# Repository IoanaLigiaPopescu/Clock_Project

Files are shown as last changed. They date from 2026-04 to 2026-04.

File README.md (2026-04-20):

BOM

Reference | Qty | Value / Part | JLC Parts Link | Datasheet
U1 | 1 | nRF52840 | https://jlcpcb.com/parts/componentSearch?searchTxt=nRF52840 | https://infocenter.nordicsemi.com/pdf/nRF52840_PS_v1.1.pdf
IC1 | 1 | BQ25180YBGR | https://jlcpcb.com/parts/componentSearch?searchTxt=BQ25180YBGR | https://www.ti.com/lit/ds/symlink/bq25180.pdf
IC2 | 1 | DRV2605YZFR | https://jlcpcb.com/parts/componentSearch?searchTxt=DRV2605YZFR | https://www.ti.com/lit/ds/symlink/drv2605.pdf
IC3 | 1 | BMA421 | https://jlcpcb.com/parts/componentSearch?searchTxt=BMA421 | https://www.bosch-sensortec.com/media/boschsensortec/downloads/datasheets/bst-bma421-ds000.pdf
IC9 | 1 | RT6160AWSC | https://jlcpcb.com/parts/componentSearch?searchTxt=RT6160AWSC | https://www.richtek.com/assets/product_file/RT6160A/DS6160A-00.pdf
U3 | 1 | MAX17048G+T10 | https://jlcpcb.com/parts/componentSearch?searchTxt=MAX17048G+T10 | https://www.analog.com/media/en/technical-documentation/data-sheets/MAX17048-MAX17049.pdf
D3 | 1 | USBLC6-2SC6Y | https://jlcpcb.com/parts/componentSearch?searchTxt=USBLC6-2SC6Y | https://www.st.com/resource/en/datasheet/usblc6-2.pdf
Q1 | 1 | DMG2305UX-7 | https://jlcpcb.com/parts/componentSearch?searchTxt=DMG2305UX-7 | https://www.diodes.com/assets/Datasheets/DMG2305UX.pdf
Q3 | 1 | SI1308EDL-T1-GE3 | https://jlcpcb.com/parts/componentSearch?searchTxt=SI1308EDL | https://www.vishay.com/docs/63399/si1308edl.pdf
J1 | 1 | 503480-2400 | https://jlcpcb.com/parts/componentSearch?searchTxt=503480-2400 | https://www.molex.com/pdm_docs/sd/5034802400_sd.pdf
J2 | 1 | TC2030-IDC | https://jlcpcb.com/parts/componentSearch?searchTxt=TC2030-IDC | https://www.tag-connect.com/wp-content/uploads/bsk-pdf-manager/TC2030-IDC-NL.pdf
J4 | 1 | KH-TYPE-C-16P | https://jlcpcb.com/parts/componentSearch?searchTxt=KH-TYPE-C-16P | https://www.kinghelm.net/uploadfiles/file/20231201/KH-TYPE-C-16P.pdf
ANT1 | 1 | 2450AT18B100E | https://jlcpcb.com/parts/componentSearch?searchTxt=2450AT18B100E | https://www.kyocera-avx.com/docs/techinfo/2450AT18B100.pdf
L7 | 1 | FTC252012SR47MBCA | https://jlcpcb.com/parts/componentSearch?searchTxt=FTC252012SR47MBCA | https://www.fenghua-advanced.com/upload/FTC252012.pdf
SW_DN,SW_ENT,SW_UP | 3 | EVP-AKE31A | https://jlcpcb.com/parts/componentSearch?searchTxt=EVP-AKE31A | https://industrial.panasonic.com/cdbs/www-data/pdf/ABH0000/ABH0000CE116.pdf
X1 | 1 | 32MHz Crystal | https://jlcpcb.com/parts/componentSearch?searchTxt=32MHz crystal 2016 | https://ecsxtal.com/store/pdf/ECS-2016MV.pdf
X2 | 1 | 32.768kHz Crystal | https://jlcpcb.com/parts/componentSearch?searchTxt=32.768kHz crystal 3215 | https://abracon.com/Resonators/ABS07.pdf
C* | multiple | Capacitors 0201/0402 | https://jlcpcb.com/parts/componentSearch?searchTxt=capacitor 0402 | https://www.murata.com/products/productdata/8796745949214/mlcc02e.pdf
R* | multiple | Resistors 0201 | https://jlcpcb.com/parts/componentSearch?searchTxt=resistor 0201 | https://www.yageo.com/upload/media/product/productsearch/datasheet/rchip/PYu-RC_Group_51_RoHS_L_12.pdf
L1,L2,L3,L5 | multiple | Inductors SMD | https://jlcpcb.com/parts/componentSearch?searchTxt=smd inductor | https://www.murata.com/products/productdata/8797098139678/ENFA0008.pdf
TP* | 14 | Test Pads | https://jlcpcb.com/parts/componentSearch?searchTxt=test pad pcb | https://www.keystone-europe.com/downloads/datasheets/5000.pdf

FUNCTIONALITATE

Proiectul este o platformă embedded portabilă bazată pe microcontroller-ul nRF52840, proiectată pentru aplicații low-power cu interfață vizuală E-Paper, alimentare din baterie Li-Po, conectivitate USB-C, feedback haptic și senzori de mișcare. Toate componentele sunt montate pe stratul Top al plăcii PCB.

Microcontroller-ul principal este nRF52840. Acesta integrează procesor ARM Cortex-M4F la 64 MHz, memorie Flash 1 MB, RAM 256 KB și transceiver radio 2.4 GHz compatibil Bluetooth Low Energy. Comunicarea RF se realizează printr-o antenă ceramică 2.45 GHz conectată printr-o rețea de adaptare de impedanță formată din L1, C3, C4 și pad opțional C22 pentru tuning RF. Oscilatorul principal extern este de 32 MHz (X1), iar oscilatorul low-power RTC este de 32.768 kHz (X2).

Interfața USB este realizată prin conector USB Type-C J4. Liniile D+ și D- sunt conectate direct la microcontroller pentru comunicație USB Full Speed. Pinii CC1 și CC2 sunt configurați prin rezistențe de 5.1 kΩ la masă pentru mod Device. Protecția ESD a liniilor USB este realizată de componenta USBLC6-2SC6Y.

Alimentarea principală provine din baterie Li-Po reîncărcabilă. Circuitul de încărcare este BQ25180YBGR, care gestionează încărcarea de la VBUS (5 V USB), controlul curentului de încărcare și monitorizarea stării prin interfață I2C. Tensiunea bateriei este disponibilă pe net-ul BAT și filtrată local prin condensatorul C39.

Conversia de tensiune este realizată de RT6160AWSC, convertor buck-boost controlat prin I2C. Acesta poate ridica sau coborî tensiunea bateriei pentru a genera rail-ul stabilizat necesar sistemului. Etajul de putere utilizează inductanța L7 și condensatorii C23, C24 la intrare respectiv C25, C32 la ieșire.

Monitorizarea nivelului bateriei este realizată de MAX17048G+T10, fuel gauge conectat la magistrala I2C. Acesta măsoară tensiunea celulei și estimează procentul de încărcare, oferind semnal ALERT către microcontroller.

Senzorul de mișcare utilizat este BMA421, accelerometru triaxial low-power. Comunicarea cu microcontroller-ul se face prin I2C, iar liniile INT1 și INT2 permit detectarea de evenimente precum mișcare, tap sau wake-up. Alimentarea senzorului este filtrată prin C18 și C19.

Feedback-ul tactil este realizat prin DRV2605YZFR, driver dedicat pentru motoare ERM/LRA. Acesta este controlat prin I2C și poate genera modele de vibrație prestabilite. Ieșirile OUT+ și OUT- sunt rutate către test point-urile TP_OP și TP_ON.

Interfața vizuală este un display E-Paper conectat prin conector FPC J1 cu 24 pini. Controlul se face de la microcontroller prin semnale dedicate (SPI și GPIO), inclusiv EPD_CS. Circuitul auxiliar al display-ului folosește MOSFET-ul Q3 și componente pasive dedicate pentru generarea tensiunilor necesare panoului.

Interfața utilizator este compusă din trei butoane tactile SW_UP, SW_ENT și SW_DN, conectate la GPIO-urile microcontroller-ului. Acestea permit navigare în meniu și control local fără dispozitive externe.

Programarea și depanarea hardware se realizează prin conectorul J2 compatibil SWD. Sunt disponibile liniile SWDIO, SWDCLK, RESET și SWO. În plus, placa include multiple test point-uri pentru 3.3V, GND, VBAT, SDA, SCL și alte semnale utile în validare.

Magistrala principală de comunicație internă este I2C, partajată între charger, convertorul DC/DC, fuel gauge, IMU și driverul haptic. Aceasta reduce numărul de pini utilizați și simplifică layout-ul PCB.

Estimarea consumului de energie depinde de modul de operare. nRF52840 în sleep poate coborî la ordinul microamperilor. În transmisie radio consumul este de ordinul miliamperilor. Display-ul E-Paper consumă aproape zero în regim static și energie doar la refresh. IMU-ul BMA421 funcționează în mod low-power la câțiva microamperi. Driverul haptic consumă semnificativ doar în timpul vibrației. Autonomia sistemului este favorizată de utilizarea componentelor low-power și a afișajului bistabil.

PCB-ul este proiectat pe 4 straturi, cu planuri dedicate de masă pentru integritate de semnal, zgomot redus și performanță RF mai bună. Toate componentele sunt plasate pe stratul superior pentru asamblare simplificată SMT.

PINI

nRF52840 este microcontroller-ul principal al sistemului și controlează toate perifericele hardware: alimentare, senzori, display, comunicație USB și debugging. Alegerea pinilor a fost făcută pentru a folosi interfețele hardware dedicate și pentru a simplifica rutarea PCB.

Pinii D+ și D- sunt conectați la conectorul USB-C prin protecția ESD D3. Aceștia sunt utilizați pentru comunicație USB nativă, programare și transfer de date.

Pinii SWDIO, SWDCLK, RESET și SWO sunt scoși la conectorul J2 pentru programare și debugging hardware.

P0.07 și P0.08 sunt utilizați ca SDA și SCL pentru magistrala I2C. Pe această magistrală sunt conectate BQ25180 (charger), RT6160A (buck-boost), MAX17048 (fuel gauge), BMA421 (IMU) și DRV2605 (driver haptic). Alegerea I2C reduce numărul de pini utilizați.

P1.08 și P1.09 sunt conectați la INT1 și INT2 de la accelerometru, pentru wake-up la mișcare și notificări hardware.

P0.11 este utilizat pentru semnal de interrupt din zona de power management.

P0.12 este utilizat pentru controlul subsistemului haptic.

P0.06 este utilizat pentru EPD_CS, semnal de selecție al display-ului E-Paper. Restul pinilor display-ului folosesc SPI și GPIO pentru control.

P0.04 și P0.05 sunt pini analogici utilizați pentru măsurători ADC, de exemplu monitorizare tensiune.

Pinul ANT este conectat la rețeaua RF L1, C3, C4 și antena ceramică. Traseul este menținut scurt pentru performanță radio bună.

XC1 și XC2 sunt conectați la cristalul de 32 MHz, iar XL1 și XL2 la cristalul de 32.768 kHz pentru RTC low-power.

PCB-ul este pe 4 straturi, cu plane de masă dedicate și toate componentele pe Top Layer. Antena este plasată la marginea plăcii cu keepout RF. Zona de alimentare este separată de zona RF, iar test point-urile pentru 3.3V, GND, VBAT, SWD și I2C permit depanare rapidă. Designul este optimizat pentru consum redus și funcționare pe baterie.

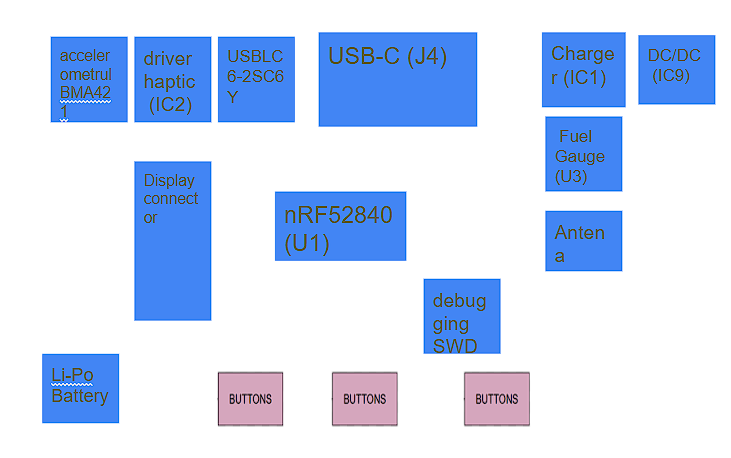
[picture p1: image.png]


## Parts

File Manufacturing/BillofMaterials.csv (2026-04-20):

Reference Designators | Quantity | Description | Package | Value | Manufacturer | Manufacturer Part Number | Vendor | Vendor Part Number | Top/Bottom
 | 1 | PCB Board | Board
ANT1 | 1 | Antennas 2.45GHz ANTENNA | 2450AT18B100E_ANTC3216X140N | 2450AT18B100E |  |  |  |  | Top
C1, C2, C17, C18 | 4 | Generic chip capacitor | NORDIC_NRF_3_RESC0201_L | 12pF |  |  |  |  | Top
C1-EP-DR | 1 | CAPACITOR, European symbol | ESP32_WROVER_EAGLE-LTSPICE_C0402 | 10µF |  |  |  |  | Top
C2-EP-DR | 1 | CAPACITOR, European symbol | ESP32_WROVER_EAGLE-LTSPICE_C0402 | 4.7uF/25V |  |  |  |  | Top
C3, C4 | 2 | Generic chip capacitor | NORDIC_NRF_3_RESC0201_L | 1pF |  |  |  |  | Top
C5, C7, C8, C12, C19 | 5 | Generic chip capacitor | NORDIC_NRF_3_RESC0201_L | 100nF |  |  |  |  | Top
C6, C14, C20, C21 | 4 | CAPACITOR, European symbol | ESP32_WROVER_EAGLE-LTSPICE_C0402 | 4.7µF |  |  |  |  | Top
C9 | 1 | Generic chip capacitor | NORDIC_NRF_3_RESC0201_L | 820pF |  |  |  |  | Top
C10, C13, C22 | 3 | Generic chip capacitor | NORDIC_NRF_3_RESC0201_L |  |  |  |  |  | Top
C11 | 1 | Generic chip capacitor | NORDIC_NRF_3_RESC0201_L | 100pF |  |  |  |  | Top
C15 | 1 | CAPACITOR, European symbol | ESP32_WROVER_EAGLE-LTSPICE_C0402 | 1.0µF |  |  |  |  | Top
C16 | 1 | Generic chip capacitor | NORDIC_NRF_3_RESC0201_L | 47nF |  |  |  |  | Top
C23, C27, C34, C42 | 4 | Check availability | CAPC0201X13N | 0.1uF |  |  |  |  | Top
C24, C39 | 2 | CAPACITOR, European symbol | ESP32_WROVER_EAGLE-LTSPICE_C0402 | 10uF |  |  |  |  | Top
C25, C33 | 2 | CAPACITOR, European symbol | ESP32_WROVER_EAGLE-LTSPICE_C0402 | 22uF |  |  |  |  | Top
C29, C30, C31, C32, C37, C38 | 6 | Check availability | CAPC0201X13N | 1uF |  |  |  |  | Top
C43 | 1 | CAPACITOR, European symbol | ESP32_WROVER_EAGLE-LTSPICE_C0402 | 4.7uF |  |  |  |  | Top
D2, D4, D5 | 3 | ON SEMICONDUCTOR - MBR0530 - DIODE, SCHOTTKY, 0.5A, 30V, SOD-123 | SOD3716X135N | MBR0530 |  |  |  |  | Top
D3 | 1 | Low Cap. ESD Protection Auto SOT-23-6 STMicroelectronics USBLC6-2SC6Y, Dual Uni-Directional TVS Diode Array, 6-Pin SOT-23 | SOT95P280X145-6N | USBLC6-2SC6Y |  |  |  |  | Top
EPD_C1, EPD_C2, EPD_C6, EPD_C7, EPD_C8, EPD_C9, EPD_C10, EPD_C11, EPD_C12 | 9 | CAPACITOR, European symbol | ESP32_WROVER_EAGLE-LTSPICE_C0402 | 1uF/50V |  |  |  |  | Top
EPD_C5 | 1 | CAPACITOR, European symbol | ESP32_WROVER_EAGLE-LTSPICE_C0402 | 0.1uF/50V |  |  |  |  | Top
IC1 | 1 | Charger IC Lithium Ion/Polymer, Lithium Iron Phosphate 8-DSBGA (1.6x1.1) | BQ25180YBGR_BGA8C40P2X4_100X155X50 | BQ25180YBGR |  |  |  |  | Top
IC2 | 1 | Haptic Driver for ERM/LRA with Built-In Library and Smart Loop Architecture | DRV2605YZFR_BGA9C50P3X3_144X144X62 | DRV2605YZFR |  |  |  |  | Top
IC3 | 1 | Accelerometers Triaxial low-g 12bit Acceleration Sensor | BMA423_BMA423 | BMA421 |  |  |  |  | Top
IC9 | 1 | Buck-Boost Regulator Positive Output Step-Up/Step-Down I2C DC-DC Controller IC 15-WL-CSP (BSC) (1.4x2.3) | RT6160AWSC_BGA15C40P3X5_140X230X60 | RT6160AWSC |  |  |  |  | Top
J1 | 1 | FFC & FPC Connectors 0.5mm FPC RA SMT Dual Contact 24Ckt | 503480-2400_5034802400 | 503480-2400 |  |  |  |  | Top
J2 | 1 | CABLE ADAPTER 6 POS | TC2030-IDC_TC2030IDC | TC2030-IDC |  |  |  |  | Top
J4 | 1 | Check availability | KINGHELM_KH-TYPE-C-16P | KH-TYPE-C-16P |  |  |  |  | Top
L1 | 1 | Generic chip inductor | NORDIC_NRF_2_RESC0402_L | 3.9nH |  |  |  |  | Top
L2 | 1 | Generic chip inductor | NORDIC_NRF_2_RESC0402_L | 10µH |  |  |  |  | Top
L3 | 1 | Generic chip inductor | NORDIC_NRF_2_RESC0402_L | 15nH |  |  |  |  | Top
L5 | 1 |  | ESP32_C6_LIBRARY_2_IND_4828-WE-TPC_WRE | 68uH |  |  |  |  | Top
L7 | 1 | SMD / SMT Inductors (Coils), L=0.47?H, L x W x T : | MLP2016SR47MT0S1_INDC2016X100N | FTC252012SR47MBCA |  |  |  |  | Top
Q1 | 1 | P-channel MOSFETs | ESP32_WROVER_SPARKFUN-DISCRETESEMI_SOT23-3 | 20V/4.2A/52mΩ/1.4W DMG2305UX-7 |  |  |  |  | Top
Q3 | 1 | MOSFET N-Ch 30V 1.5A TrenchFET SC70 Vishay Si1308EDL-T1-GE3 N-channel MOSFET Transistor, 1.5 A, 30 V, 3-Pin SC-70 | SOT65P210X110-3N | SI1308EDL-T1-GE3 |  |  |  |  | Top
R_PWR_EPD, R2_EP_DR | 2 | 7.68k 0201 Thin Film Surface Mount Fixed Resistor +/-0.5% 0.031W CPF0201D7K68C1 | CPF0201D7K68C1_0201 | 10K |  |  |  |  | Top
R_TYPE_SEL | 1 | 7.68k 0201 Thin Film Surface Mount Fixed Resistor +/-0.5% 0.031W CPF0201D7K68C1 | CPF0201D7K68C1_0201 | 2.2 |  |  |  |  | Top
R1_EP_DR | 1 | 7.68k 0201 Thin Film Surface Mount Fixed Resistor +/-0.5% 0.031W CPF0201D7K68C1 | CPF0201D7K68C1_0201 | 0.47 |  |  |  |  | Top
R1_USB, R2_USB | 2 | 7.68k 0201 Thin Film Surface Mount Fixed Resistor +/-0.5% 0.031W CPF0201D7K68C1 | CPF0201D7K68C1_0201 | 5K1 |  |  |  |  | Top
R2, R3, R4 | 3 | 7.68k 0201 Thin Film Surface Mount Fixed Resistor +/-0.5% 0.031W CPF0201D7K68C1 | CPF0201D7K68C1_0201 | 0 |  |  |  |  | Top
R5, R7, R8, R9 | 4 | 7.68k 0201 Thin Film Surface Mount Fixed Resistor +/-0.5% 0.031W CPF0201D7K68C1 | CPF0201D7K68C1_0201 | 10k |  |  |  |  | Top
R17, R18 | 2 | 7.68k 0201 Thin Film Surface Mount Fixed Resistor +/-0.5% 0.031W CPF0201D7K68C1 | CPF0201D7K68C1_0201 | 3K3 |  |  |  |  | Top
SJ1 | 1 | SMD solder JUMPER | JUMPER_SJ |  |  |  |  |  | Top
SW_DN, SW_ENT, SW_UP | 3 |  | SW_EVP-AKE31A_PAN | 2025-10-22_07-23-44_LIBRARY_EVP-AKE31ASW_EVP-AKE31A_PAN |  |  |  |  | Top
TP_3.3V, TP_3V3, TP_BAT_GND, TP_GND, TP_ON, TP_OP, TP_RESET, TP_SCL, TP_SDA, TP_SWDCLK, TP_SWDIO, TP_SWO, TP_VBAT, TP_VREG | 14 | Test pad | HECTOR_WATCH_1_TP20R | HECTOR_WATCH_1_TPTP20R |  |  |  |  | Top
U1 | 1 | nRF52840 | NORDIC_NRF_4_AQFN50P700X700X85_HS-74N | NRF52840_QF |  |  |  |  | Top
U3 | 1 | Check availability | SON50P200X200X80-9N | MAX17048G+T10 |  |  |  |  | Top
X1 | 1 |  | NORDIC_NRF_BT-XTAL_2016_N | 32MHz |  |  |  |  | Top
X2 | 1 |  | NORDIC_NRF_1_XTAL_3215_N | 32.768kHz |  |  |  |  | Top

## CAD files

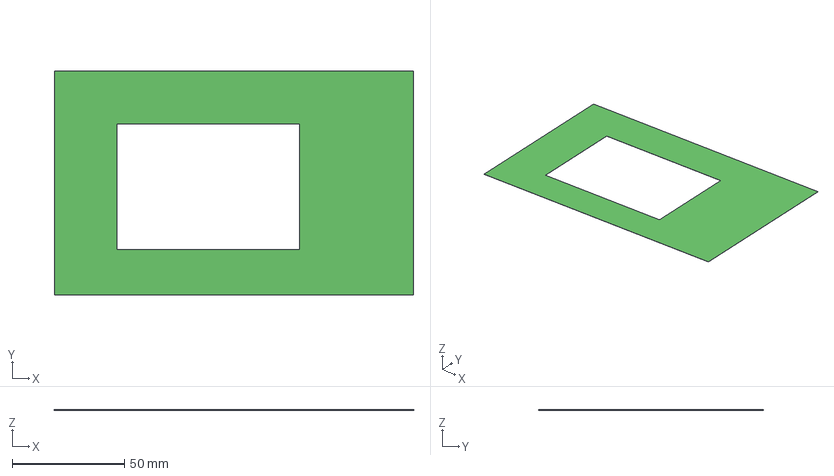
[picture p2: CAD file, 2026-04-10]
3d/1-soldermask.step
160.0 x 100.0 x 0.0804 mm

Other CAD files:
pcb/pcb.f3d

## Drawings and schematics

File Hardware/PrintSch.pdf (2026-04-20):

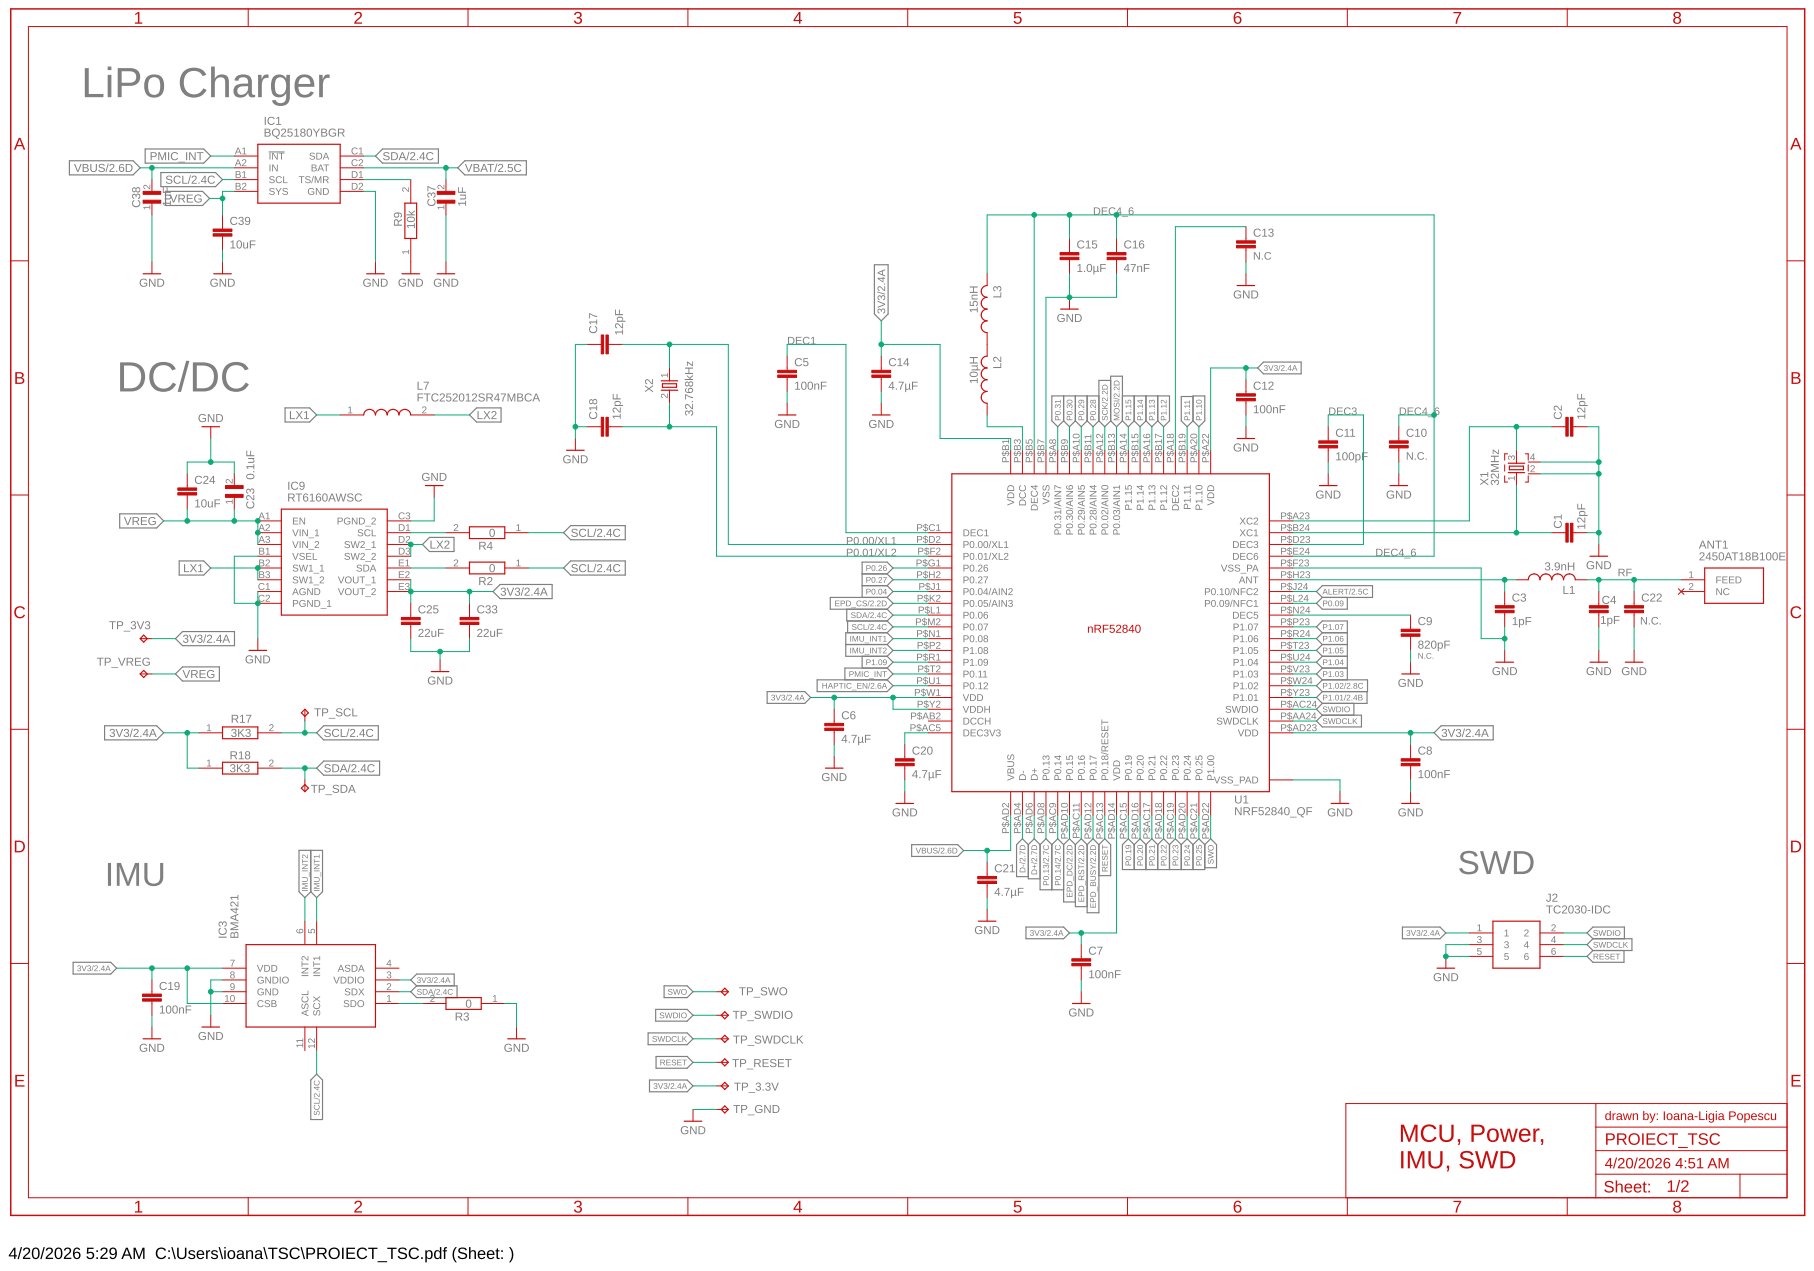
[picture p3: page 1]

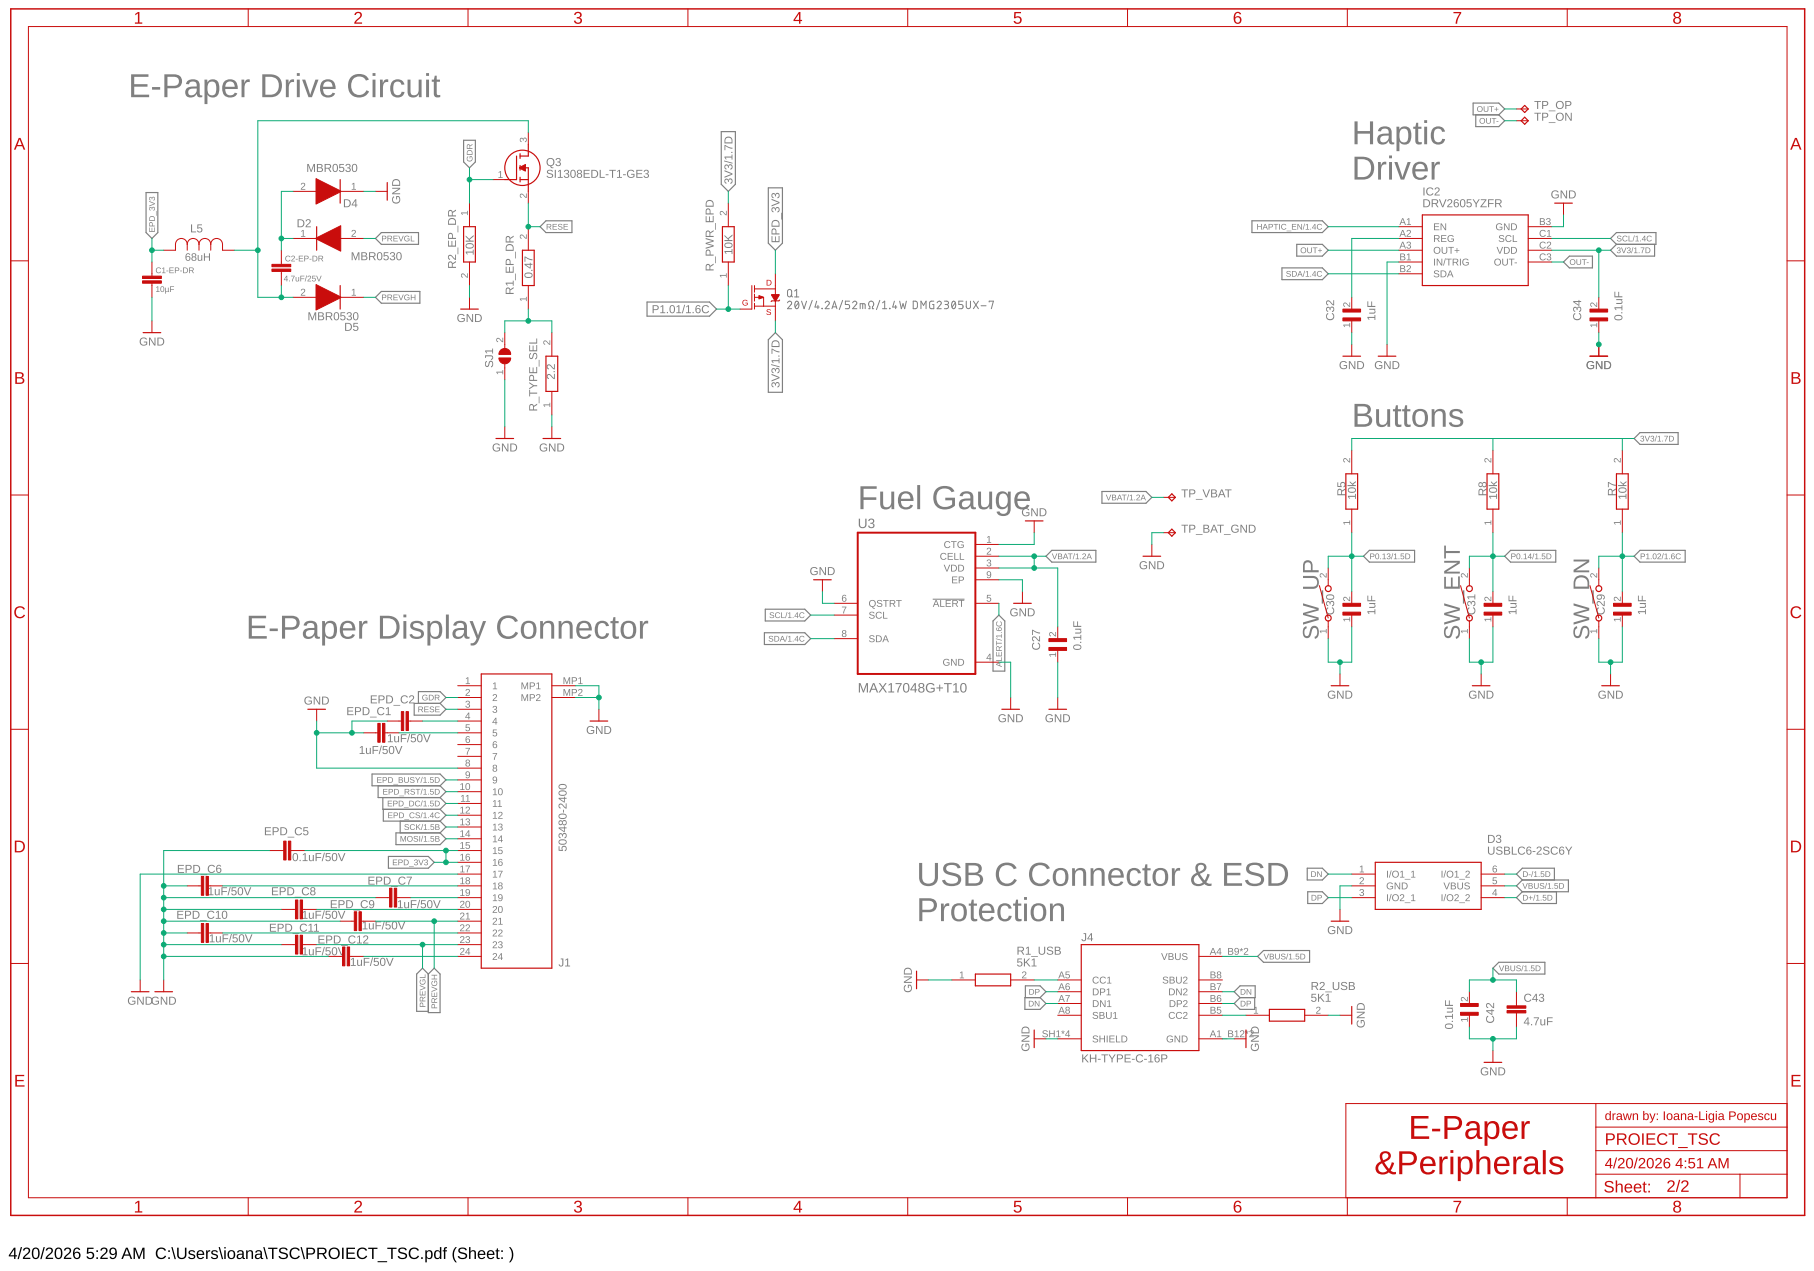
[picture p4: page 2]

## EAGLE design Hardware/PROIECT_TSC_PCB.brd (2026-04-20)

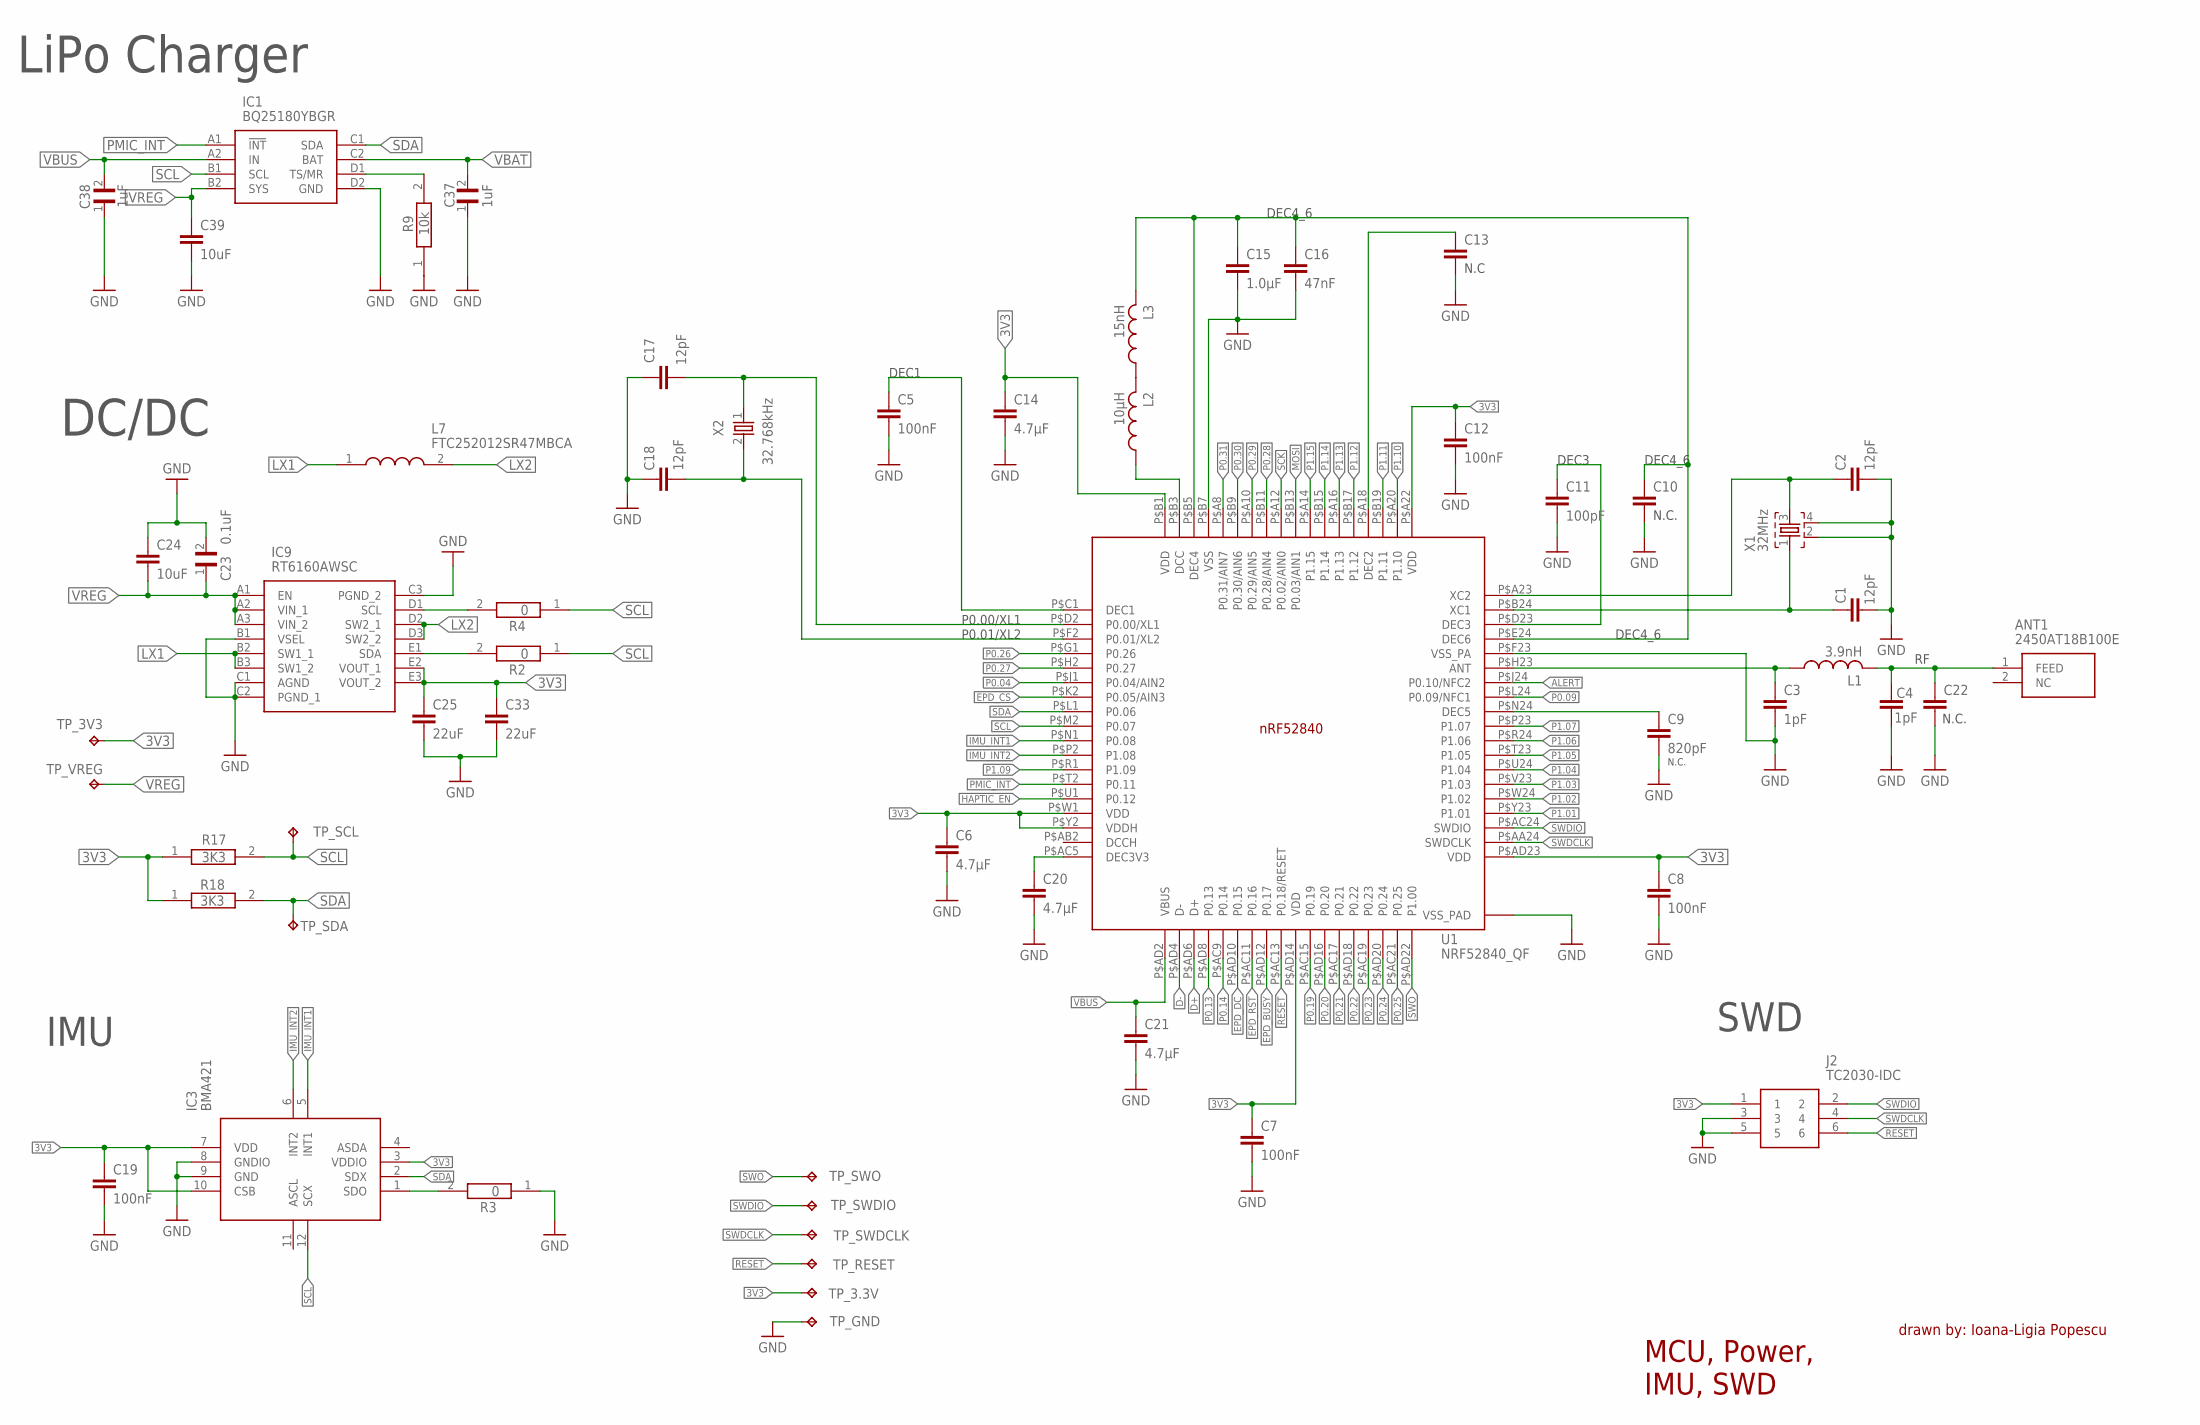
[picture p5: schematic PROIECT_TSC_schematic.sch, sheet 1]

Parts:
ANT1: 2450AT18B100E; 2450AT18B100E_ANTC3216X140N
C1, C2, C17, C18: 12pF; NORDIC_NRF_3_RESC0201_L
C3, C4: 1pF; NORDIC_NRF_3_RESC0201_L
C5, C7, C8, C12, C19: 100nF; NORDIC_NRF_3_RESC0201_L
C6, C14, C20, C21: 4.7µF; ESP32_C6_LIBRARY_1_ESP32_WROVER_EAGLE-LTSPICE_C0402
C9: 820pF; NORDIC_NRF_3_RESC0201_L
C10, C13, C22: NORDIC_NRF_3_CAPACITOR_0201_L; NORDIC_NRF_3_RESC0201_L
C11: 100pF; NORDIC_NRF_3_RESC0201_L
C15: 1.0µF; ESP32_C6_LIBRARY_1_ESP32_WROVER_EAGLE-LTSPICE_C0402
C16: 47nF; NORDIC_NRF_3_RESC0201_L
C23: 0.1uF; GRM011R60J152KE01L_2_CAPC0201X13N
C24, C39: 10uF; ESP32_C6_LIBRARY_1_ESP32_WROVER_EAGLE-LTSPICE_C0402
C25, C33: 22uF; ESP32_C6_LIBRARY_1_ESP32_WROVER_EAGLE-LTSPICE_C0402
C37, C38: 1uF; GRM011R60J152KE01L_2_CAPC0201X13N
IC1: BQ25180YBGR; BQ25180YBGR_BGA8C40P2X4_100X155X50
IC3: BMA421; BMA423_BMA423
IC9: RT6160AWSC; RT6160AWSC_BGA15C40P3X5_140X230X60
J2: TC2030-IDC; TC2030-IDC_TC2030IDC
L1: 3.9nH; NORDIC_NRF_2_RESC0402_L
L2: 10µH; NORDIC_NRF_2_RESC0402_L
L3: 15nH; NORDIC_NRF_2_RESC0402_L
L7: FTC252012SR47MBCA; MLP2016SR47MT0S1_INDC2016X100N
R2, R3, R4: 0; CPF0201D7K68C1_0201
R9: 10k; CPF0201D7K68C1_0201
R17, R18: 3K3; CPF0201D7K68C1_0201
TP_3.3V, TP_3V3: HECTOR_WATCH_1_TPTP20R; HECTOR_WATCH_1_TP20R
TP_GND: HECTOR_WATCH_1_TPTP20R; HECTOR_WATCH_1_TP20R
TP_RESET: HECTOR_WATCH_1_TPTP20R; HECTOR_WATCH_1_TP20R
TP_SCL: HECTOR_WATCH_1_TPTP20R; HECTOR_WATCH_1_TP20R
TP_SDA: HECTOR_WATCH_1_TPTP20R; HECTOR_WATCH_1_TP20R
TP_SWDCLK: HECTOR_WATCH_1_TPTP20R; HECTOR_WATCH_1_TP20R
TP_SWDIO: HECTOR_WATCH_1_TPTP20R; HECTOR_WATCH_1_TP20R
TP_SWO: HECTOR_WATCH_1_TPTP20R; HECTOR_WATCH_1_TP20R
TP_VREG: HECTOR_WATCH_1_TPTP20R; HECTOR_WATCH_1_TP20R
U1: NRF52840_QF; NORDIC_NRF_4_AQFN50P700X700X85_HS-74N
X1: 32MHz; NORDIC_NRF_BT-XTAL_2016_N
X2: 32.768kHz; NORDIC_NRF_1_XTAL_3215_N

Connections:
3V3: C6.1, C7.1, C8.1, C12.1, C14.1, C19.1, C25.1, C33.1, IC3.3 (VDDIO), IC3.7 (VDD), IC3.10 (CSB), IC9.E2 (VOUT_1), IC9.E3 (VOUT_2), J2.1, R17.1, R18.1, TP_3.3V.TP, TP_3V3.TP, U1.P$A22 (VDD), U1.P$AD14 (VDD), U1.P$AD23 (VDD), U1.P$B1 (VDD), U1.P$W1 (VDD), U1.P$Y2 (VDDH); also elsewhere on the board
ALERT: U1.P$J24 (P0.10/NFC2); also elsewhere on the board
D+: U1.P$AD6 (D+); also elsewhere on the board
D-: U1.P$AD4 (D-); also elsewhere on the board
EPD_BUSY: U1.P$AD12 (P0.17); also elsewhere on the board
EPD_CS: U1.P$K2 (P0.05/AIN3); also elsewhere on the board
EPD_DC: U1.P$AD10 (P0.15); also elsewhere on the board
EPD_RST: U1.P$AC11 (P0.16); also elsewhere on the board
GND: C1.1, C2.2, C3.2, C4.1, C5.2, C6.2, C7.2, C8.2, C9.2, C10.2, C11.2, C12.2, C13.2, C14.2, C15.2, C16.2, C17.2, C18.1, C19.2, C20.2, C21.2, C22.2, C23.2, C24.1, C25.2, C33.2, C37.1, C38.1, C39.2, IC1.D2 (GND), IC3.8 (GNDIO), IC3.9 (GND), IC9.B1 (VSEL), IC9.C1 (AGND), IC9.C2 (PGND_1), IC9.C3 (PGND_2), J2.3, J2.5, R3.1, R9.1, TP_GND.TP, U1.P$74 (VSS_PAD), U1.P$75 (VSS_PAD), U1.P$76 (VSS_PAD), U1.P$77 (VSS_PAD), U1.P$78 (VSS_PAD), U1.P$79 (VSS_PAD), U1.P$80 (VSS_PAD), U1.P$81 (VSS_PAD), U1.P$82 (VSS_PAD), U1.P$83 (VSS_PAD), U1.P$84 (VSS_PAD), U1.P$85 (VSS_PAD), U1.P$86 (VSS_PAD), U1.P$87 (VSS_PAD), U1.P$88 (VSS_PAD), U1.P$89 (VSS_PAD), U1.P$90 (VSS_PAD), U1.P$B7 (VSS), U1.P$F23 (VSS_PA), X1.2, X1.4; also elsewhere on the board
HAPTIC_EN: U1.P$U1 (P0.12); also elsewhere on the board
IMU_INT1: IC3.5 (INT1), U1.P$N1 (P0.08)
IMU_INT2: IC3.6 (INT2), U1.P$P2 (P1.08)
LX1: IC9.B2 (SW1_1), IC9.B3 (SW1_2), L7.1
LX2: IC9.D2 (SW2_1), IC9.D3 (SW2_2), L7.2
MOSI: U1.P$B13 (P0.03/AIN1); also elsewhere on the board
unnamed: IC1.D1 (TS/MR), R9.2
unnamed: IC9.D1 (SCL), R4.2
unnamed: C11.1, U1.P$D23 (DEC3)
unnamed: IC9.E1 (SDA), R2.2
unnamed: C13.1, U1.P$A18 (DEC2)
unnamed: C2.1, U1.P$A23 (XC2), X1.3
unnamed: C1.2, U1.P$B24 (XC1), X1.1
unnamed: L2.1, U1.P$B3 (DCC)
unnamed: L2.2, L3.1
unnamed: C10.1, C15.1, C16.1, L3.2, U1.P$B5 (DEC4), U1.P$E24 (DEC6)
unnamed: C9.1, U1.P$N24 (DEC5)
unnamed: C3.1, L1.1, U1.P$H23 (ANT)
unnamed: ANT1.1 (FEED), C4.2, C22.1, L1.2
unnamed: C5.1, U1.P$C1 (DEC1)
unnamed: C17.1, U1.P$D2 (P0.00/XL1), X2.1
unnamed: C18.2, U1.P$F2 (P0.01/XL2), X2.2
unnamed: C20.1, U1.P$AC5 (DEC3V3)
unnamed: IC3.1 (SDO), R3.2
P0.04: U1.P$J1 (P0.04/AIN2)
P0.09: U1.P$L24 (P0.09/NFC1)
P0.13: U1.P$AD8 (P0.13); also elsewhere on the board
P0.14: U1.P$AC9 (P0.14); also elsewhere on the board
P0.19: U1.P$AC15 (P0.19)
P0.20: U1.P$AD16 (P0.20)
P0.21: U1.P$AC17 (P0.21)
P0.22: U1.P$AD18 (P0.22)
P0.23: U1.P$AC19 (P0.23)
P0.24: U1.P$AD20 (P0.24)
P0.25: U1.P$AC21 (P0.25)
P0.26: U1.P$G1 (P0.26)
P0.27: U1.P$H2 (P0.27)
P0.28: U1.P$B11 (P0.28/AIN4)
P0.29: U1.P$A10 (P0.29/AIN5)
P0.30: U1.P$B9 (P0.30/AIN6)
P0.31: U1.P$A8 (P0.31/AIN7)
P1.01: U1.P$Y23 (P1.01); also elsewhere on the board
P1.02: U1.P$W24 (P1.02); also elsewhere on the board
P1.03: U1.P$V23 (P1.03)
P1.04: U1.P$U24 (P1.04)
P1.05: U1.P$T23 (P1.05)
P1.06: U1.P$R24 (P1.06)
P1.07: U1.P$P23 (P1.07)
P1.09: U1.P$R1 (P1.09)
P1.10: U1.P$A20 (P1.10)
P1.11: U1.P$B19 (P1.11)
P1.12: U1.P$B17 (P1.12)
P1.13: U1.P$A16 (P1.13)
P1.14: U1.P$B15 (P1.14)
P1.15: U1.P$A14 (P1.15)
PMIC_INT: IC1.A1 (!INT), U1.P$T2 (P0.11)
RESET: J2.6, TP_RESET.TP, U1.P$AC13 (P0.18/RESET)
SCK: U1.P$A12 (P0.02/AIN0); also elsewhere on the board
SCL: IC1.B1 (SCL), IC3.12 (SCX), R2.1, R4.1, R17.2, TP_SCL.TP, U1.P$M2 (P0.07); also elsewhere on the board
SDA: IC1.C1 (SDA), IC3.2 (SDX), R18.2, TP_SDA.TP, U1.P$L1 (P0.06); also elsewhere on the board
SWDCLK: J2.4, TP_SWDCLK.TP, U1.P$AA24 (SWDCLK)
SWDIO: J2.2, TP_SWDIO.TP, U1.P$AC24 (SWDIO)
SWO: TP_SWO.TP, U1.P$AD22 (P1.00)
VBAT: C37.2, IC1.C2 (BAT); also elsewhere on the board
VBUS: C21.1, C38.2, IC1.A2 (IN), U1.P$AD2 (VBUS); also elsewhere on the board
VREG: C23.1, C24.2, C39.1, IC1.B2 (SYS), IC9.A1 (EN), IC9.A2 (VIN_1), IC9.A3 (VIN_2), TP_VREG.TP

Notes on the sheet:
LiPo Charger
DC/DC
N.C.
DEC4_6
DEC3
N.C
DEC1
P0.00/XL1
P0.01/XL2
SWD
IMU
MCU, Power, IMU, SWD
drawn by: Ioana-Ligia Popescu

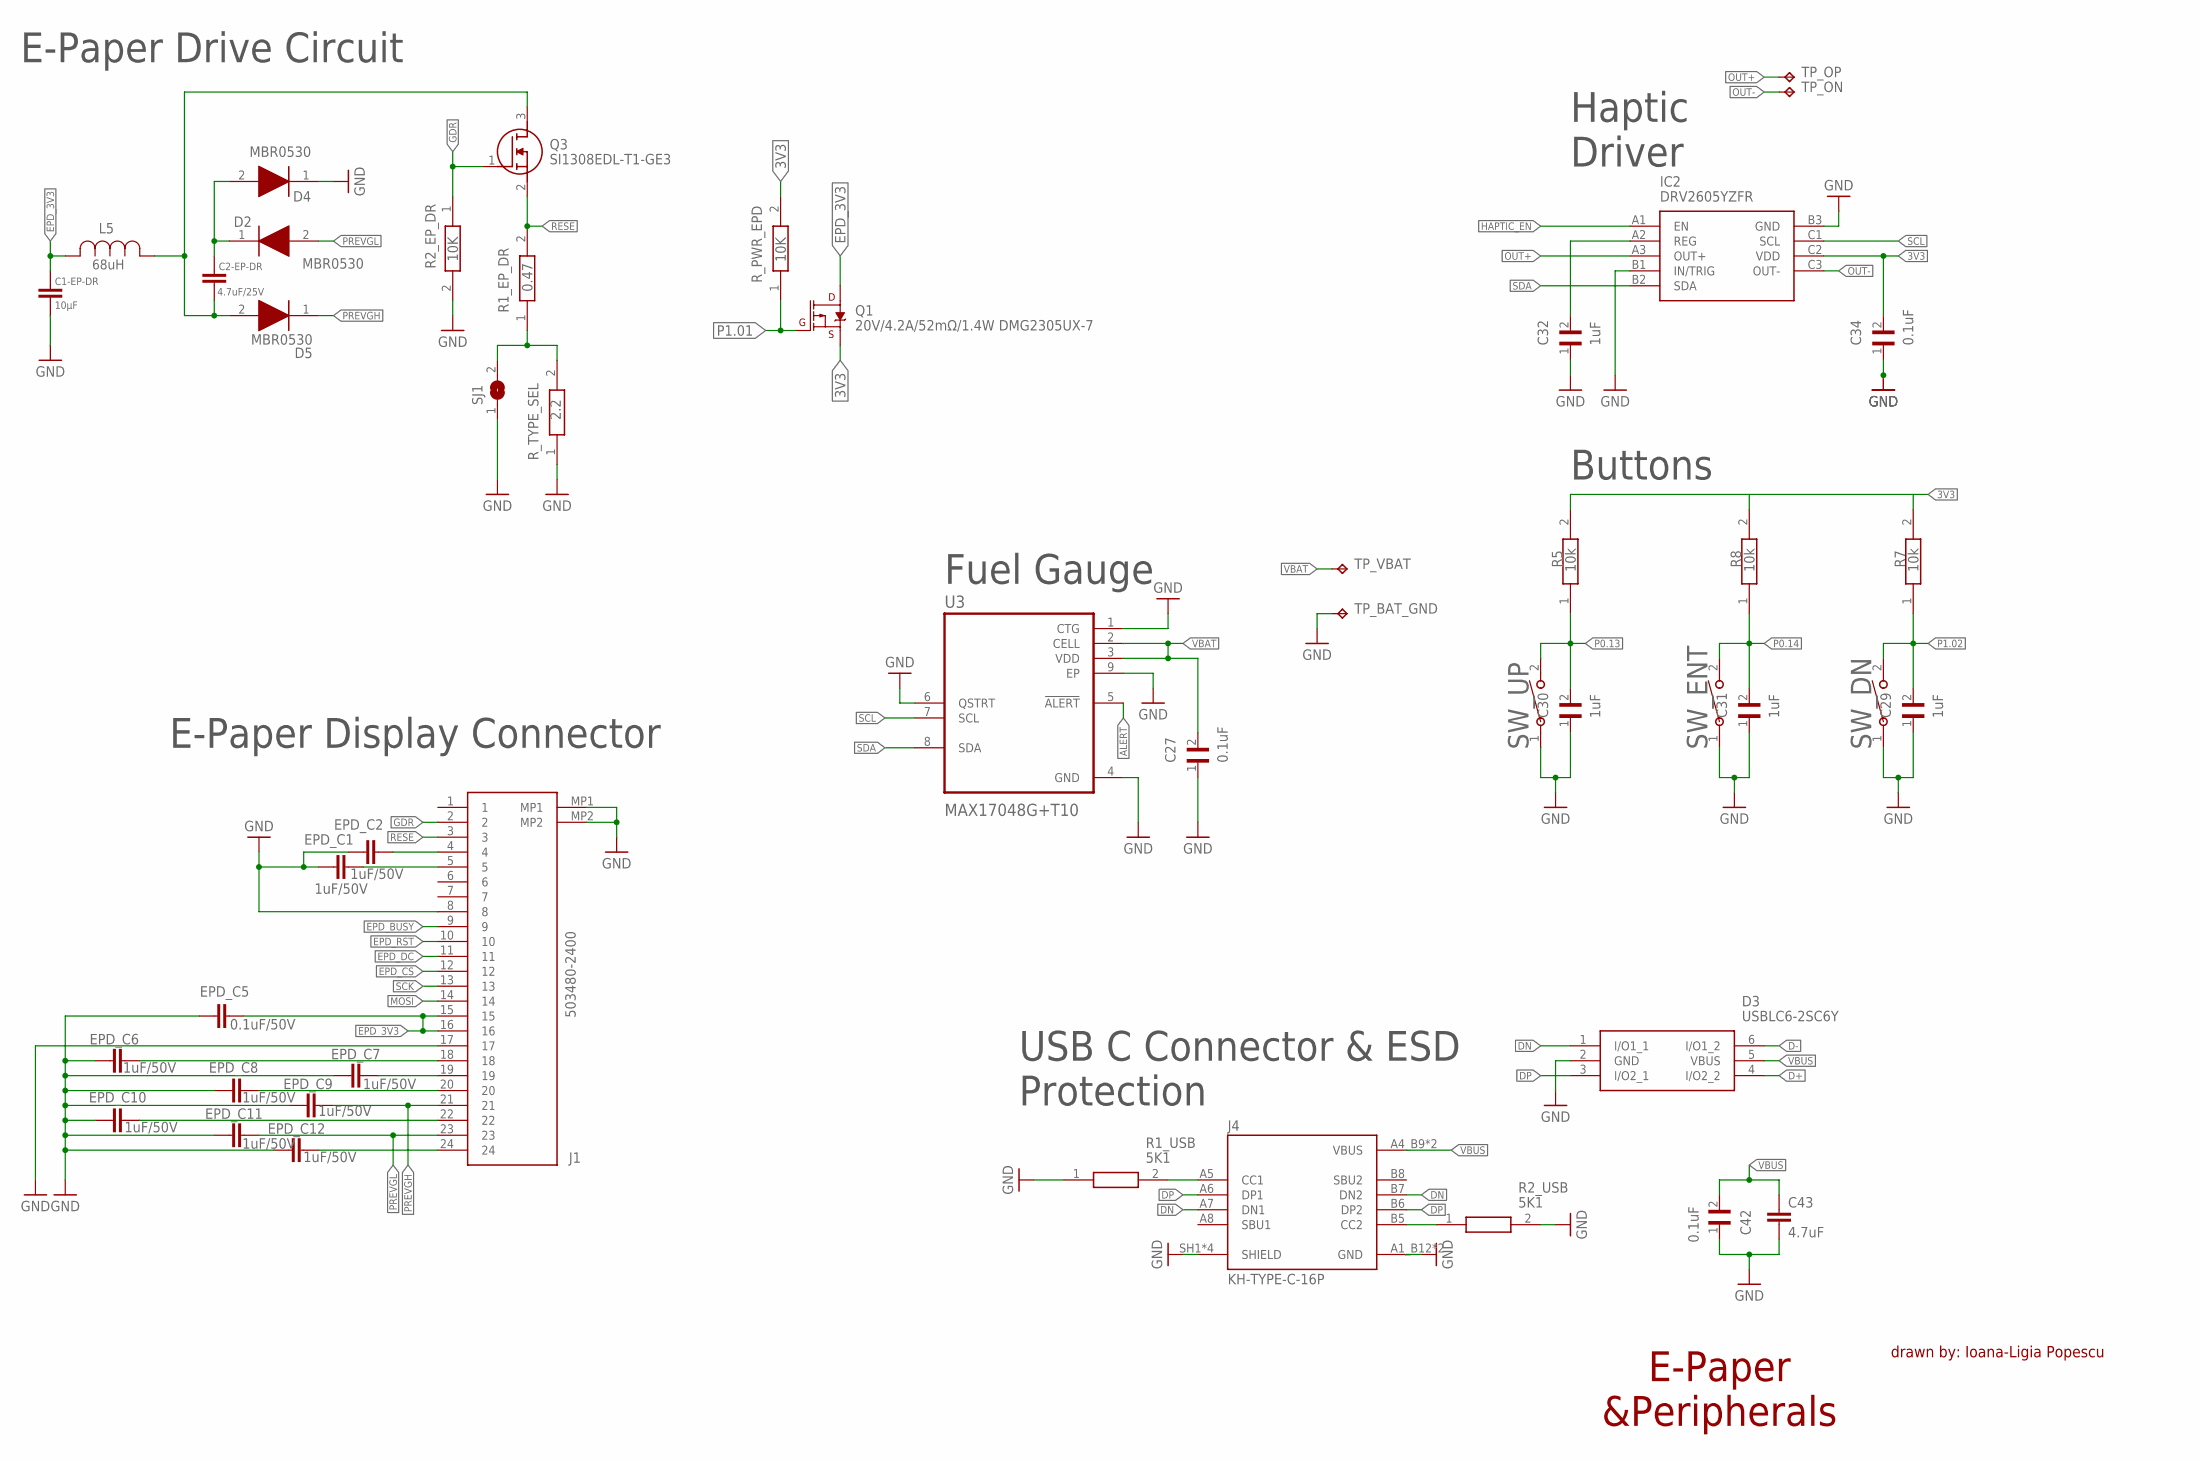
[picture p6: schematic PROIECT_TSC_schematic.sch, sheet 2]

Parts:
C1-EP-DR: 10µF; ESP32_C6_LIBRARY_1_ESP32_WROVER_EAGLE-LTSPICE_C0402
C2-EP-DR: 4.7uF/25V; ESP32_C6_LIBRARY_1_ESP32_WROVER_EAGLE-LTSPICE_C0402
C27, C34, C42: 0.1uF; GRM011R60J152KE01L_2_CAPC0201X13N
C29, C30, C31, C32: 1uF; GRM011R60J152KE01L_2_CAPC0201X13N
C43: 4.7uF; ESP32_C6_LIBRARY_1_ESP32_WROVER_EAGLE-LTSPICE_C0402
D2, D4, D5: MBR0530; ESP32_C6_LIBRARY_5_SOD3716X135N
D3: USBLC6-2SC6Y; ESP32_C6_LIBRARY_3_SOT95P280X145-6N
EPD_C1, EPD_C2, EPD_C6, EPD_C7, EPD_C8, EPD_C9, EPD_C10, EPD_C11, EPD_C12: 1uF/50V; ESP32_C6_LIBRARY_1_ESP32_WROVER_EAGLE-LTSPICE_C0402
EPD_C5: 0.1uF/50V; ESP32_C6_LIBRARY_1_ESP32_WROVER_EAGLE-LTSPICE_C0402
IC2: DRV2605YZFR; DRV2605YZFR_BGA9C50P3X3_144X144X62
J1: 503480-2400; 503480-2400_5034802400
J4: KH-TYPE-C-16P; KH-TYPE-C-16P_KINGHELM_KH-TYPE-C-16P
L5: 68uH; ESP32_C6_LIBRARY_2_IND_4828-WE-TPC_WRE
Q1: 20V/4.2A/52mΩ/1.4W DMG2305UX-7; ESP32_C6_LIBRARY_4_ESP32_C6_LIBRARY_4_ESP32_C6_LIBRARY_4_ES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
Q3: SI1308EDL-T1-GE3; ESP32_C6_LIBRARY_6_SOT65P210X110-3N
R1_EP_DR: 0.47; CPF0201D7K68C1_0201
R1_USB, R2_USB: 5K1; CPF0201D7K68C1_0201
R2_EP_DR: 10K; CPF0201D7K68C1_0201
R5, R7, R8: 10k; CPF0201D7K68C1_0201
R_PWR_EPD: 10K; CPF0201D7K68C1_0201
R_TYPE_SEL: 2.2; CPF0201D7K68C1_0201
SJ1: ESP32_C6_LIBRARY_7_JUMPER_SJ
SW_DN: 2025-10-22_07-23-44_LIBRARY_EVP-AKE31ASW_EVP-AKE3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; 2025-10-22_07-23-44_LIBRARY_SW_EVP-AKE31A_PAN
SW_ENT: 2025-10-22_07-23-44_LIBRARY_EVP-AKE31ASW_EVP-AKE3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; 2025-10-22_07-23-44_LIBRARY_SW_EVP-AKE31A_PAN
SW_UP: 2025-10-22_07-23-44_LIBRARY_EVP-AKE31ASW_EVP-AKE3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; 2025-10-22_07-23-44_LIBRARY_SW_EVP-AKE31A_PAN
TP_BAT_GND: HECTOR_WATCH_1_TPTP20R; HECTOR_WATCH_1_TP20R
TP_ON: HECTOR_WATCH_1_TPTP20R; HECTOR_WATCH_1_TP20R
TP_OP: HECTOR_WATCH_1_TPTP20R; HECTOR_WATCH_1_TP20R
TP_VBAT: HECTOR_WATCH_1_TPTP20R; HECTOR_WATCH_1_TP20R
U3: MAX17048G+T10; ESP32_C6_LIBRARY_SON50P200X200X80-9N

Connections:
3V3: C34.2, IC2.C2 (VDD), Q1.2 (S), R5.2, R_PWR_EPD.2; also elsewhere on the board
ALERT: U3.5 (!ALERT); also elsewhere on the board
D+: D3.4 (I/O2_2); also elsewhere on the board
D-: D3.6 (I/O1_2); also elsewhere on the board
DN: D3.1 (I/O1_1), J4.A7 (DN1), J4.B7 (DN2)
DP: D3.3 (I/O2_1), J4.A6 (DP1), J4.B6 (DP2)
EPD_3V3: C1-EP-DR.1, EPD_C5.2, J1.15, J1.16, L5.2, Q1.3 (D)
EPD_BUSY: J1.9; also elsewhere on the board
EPD_CS: J1.12; also elsewhere on the board
EPD_DC: J1.11; also elsewhere on the board
EPD_RST: J1.10; also elsewhere on the board
GDR: J1.2, Q3.1 (G), R2_EP_DR.1
GND: C1-EP-DR.2, C27.1, C29.1, C30.1, C31.1, C32.1, C34.1, C42.1, C43.2, D3.2 (GND), D4.1 (K), EPD_C1.1, EPD_C2.1, EPD_C5.1, EPD_C6.1, EPD_C7.1, EPD_C8.1, EPD_C9.1, EPD_C10.1, EPD_C11.1, EPD_C12.1, IC2.B1 (IN/TRIG), IC2.B3 (GND), J1.8, J1.17, J1.MP1, J1.MP2, J4.A1_B12 (GND), J4.A12_B1 (GND), J4.SH1 (SHIELD), J4.SH2 (SHIELD), J4.SH3 (SHIELD), J4.SH4 (SHIELD), R1_USB.1, R2_EP_DR.2, R2_USB.2, R_TYPE_SEL.1, SJ1.1, SW_DN.1, SW_ENT.1, SW_UP.1, TP_BAT_GND.TP, U3.1 (CTG), U3.4 (GND), U3.6 (QSTRT), U3.9 (EP); also elsewhere on the board
HAPTIC_EN: IC2.A1 (EN); also elsewhere on the board
MOSI: J1.14; also elsewhere on the board
unnamed: C2-EP-DR.2, D5.2 (A), L5.1, Q3.3 (D)
unnamed: C2-EP-DR.1, D2.1 (K), D4.2 (A)
unnamed: R1_EP_DR.1, R_TYPE_SEL.2, SJ1.2
unnamed: EPD_C2.2, J1.4
unnamed: EPD_C1.2, J1.5
unnamed: J4.B5 (CC2), R2_USB.1
unnamed: C32.2, IC2.A2 (REG)
unnamed: J4.A5 (CC1), R1_USB.2
unnamed: EPD_C6.2, J1.18
unnamed: EPD_C7.2, J1.19
unnamed: EPD_C8.2, J1.20
unnamed: EPD_C10.2, J1.22
unnamed: EPD_C12.2, J1.24
OUT+: IC2.A3 (OUT+), TP_OP.TP
OUT-: IC2.C3 (OUT-), TP_ON.TP
P0.13: C30.2, R5.1, SW_UP.2; also elsewhere on the board
P0.14: C31.2, R8.1, SW_ENT.2; also elsewhere on the board
P1.01: Q1.1 (G), R_PWR_EPD.1; also elsewhere on the board
P1.02: C29.2, R7.1, SW_DN.2; also elsewhere on the board
PREVGH: D5.1 (K), EPD_C9.2, J1.21
PREVGL: D2.2 (A), EPD_C11.2, J1.23
RESE: J1.3, Q3.2 (S), R1_EP_DR.2
SCK: J1.13; also elsewhere on the board
SCL: IC2.C1 (SCL), U3.7 (SCL); also elsewhere on the board
SDA: IC2.B2 (SDA), U3.8 (SDA); also elsewhere on the board
VBAT: C27.2, TP_VBAT.TP, U3.2 (CELL), U3.3 (VDD); also elsewhere on the board
VBUS: C42.2, C43.1, D3.5 (VBUS), J4.A4_B9 (VBUS), J4.A9_B4 (VBUS); also elsewhere on the board

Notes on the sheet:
E-Paper Drive Circuit
Haptic Driver
E-Paper Display Connector
USB C Connector & ESD Protection
Buttons
Fuel Gauge
E-Paper &Peripherals
drawn by: Ioana-Ligia Popescu

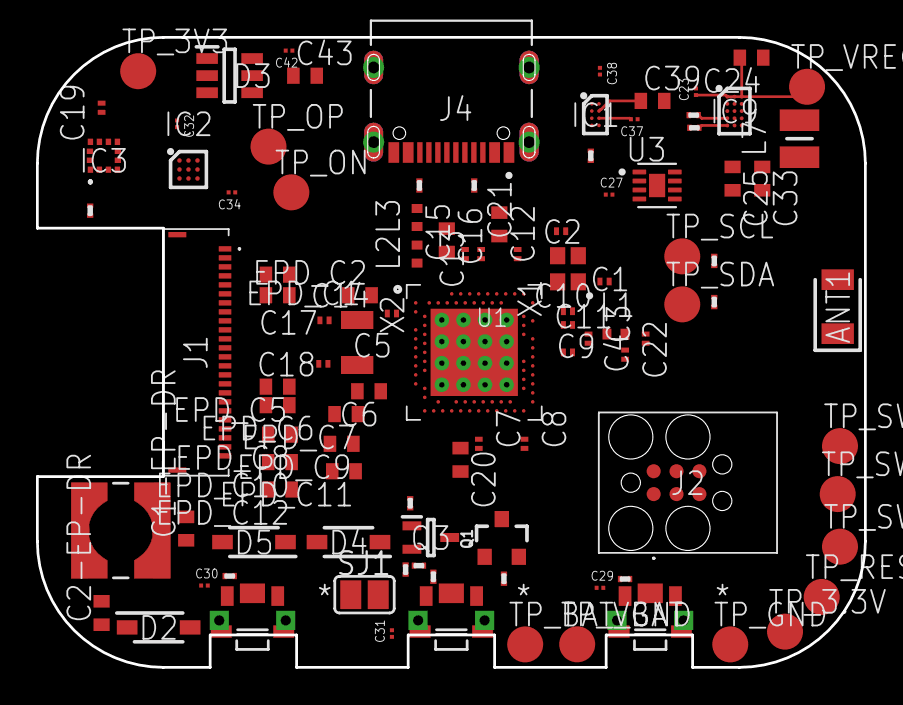
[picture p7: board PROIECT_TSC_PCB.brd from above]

Board: 4 copper layers, 46.0 x 35.0 mm, 105 parts (0 on the bottom side), 70 nets.

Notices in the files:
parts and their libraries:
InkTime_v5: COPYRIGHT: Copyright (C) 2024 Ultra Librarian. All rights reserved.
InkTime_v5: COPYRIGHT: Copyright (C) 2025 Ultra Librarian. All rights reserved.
